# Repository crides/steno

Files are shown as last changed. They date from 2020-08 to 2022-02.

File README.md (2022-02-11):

# Steno

If you are here, you are probably looking for my embedded steno work. You can find the PCB design and production files for my steno keyboards (mostly known as the batwing or just bat) in the `pcb/` directory, and the embedded steno firmware (Kolibri) and the dictionary compiler in the `qmk/` and `compiler/` directories.

The detailed info for each can be found in their own READMEs, [boards](pcb/README.md) [firmware](qmk/README.md) and [dictionary compiler](compiler/README.md).

There's a overly simple and fairly outdated [demo](https://youtu.be/yKcQSxQE79Y).

## What's Steno(graphy)?

If you don't know what stenography is, it's a short hand system primarily used by court reporters and captioners for note taking at a very high speeds. The English stenography system uses a special keyboard with only 23 keys on it, and the keys are meant to be pressed at the same time, producing combinations called chords. When combined together and translated through an engine, it can be used to input at very high speeds (professional stenographers need to reach above 225 wpm). Due to the price of commercial steno machines, free and open source alternatives started appearing, the most prominent among which is [Plover](https://github.com/openstenoproject/plover), which acts as a keyboard emulator that can translate chords from a \$20 gaming keyboard into words efficiently. A lot of ideas here are inspired by Plover.

If you want to go a bit more in depth, you should check out [this video](https://www.youtube.com/watch?v=JsRTTD9k2ME) by Aerick, or this [PyCon talk](https://www.youtube.com/watch?v=Wpv-Qb-dB6g) by Mirabai Knight, the creator of Plover.

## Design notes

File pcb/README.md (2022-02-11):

# Embedded steno boards

These are the steno keyboards I designed and built, almost all of which has some form of hardware support for a embedded steno engine. These are just a list for more or less steno centric designs though, you can find my other boards using embedded steno like the [fissure v3](https://github.com/crides/fissure) and the [fusion](https://github.com/crides/fusion).

## Version 4

Version 4 is/are being designed as a more general board for others to use. There have been some people in the community requested me to sell some form of embedded steno board, and hardware vendors have yet to integrate the system (which on hardware is at least a flash chip). So these design(s) are meant to be easier to manufacture or assemble for the people printing their own.

## Version 3b / Bluebat

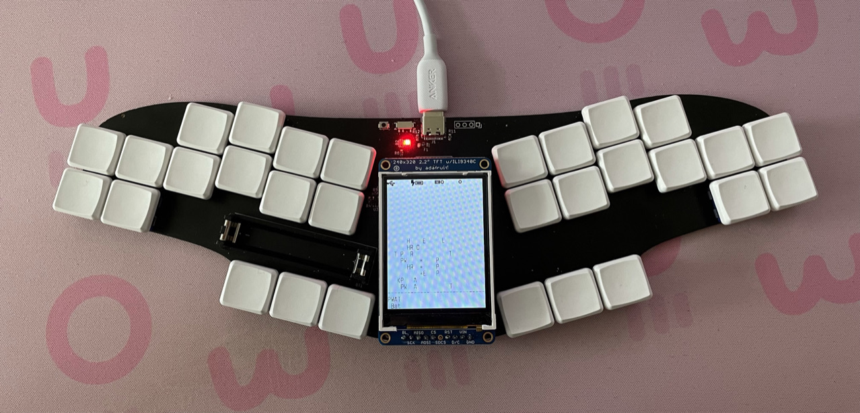
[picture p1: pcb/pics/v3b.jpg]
Picture from Jen/@sammdot: 

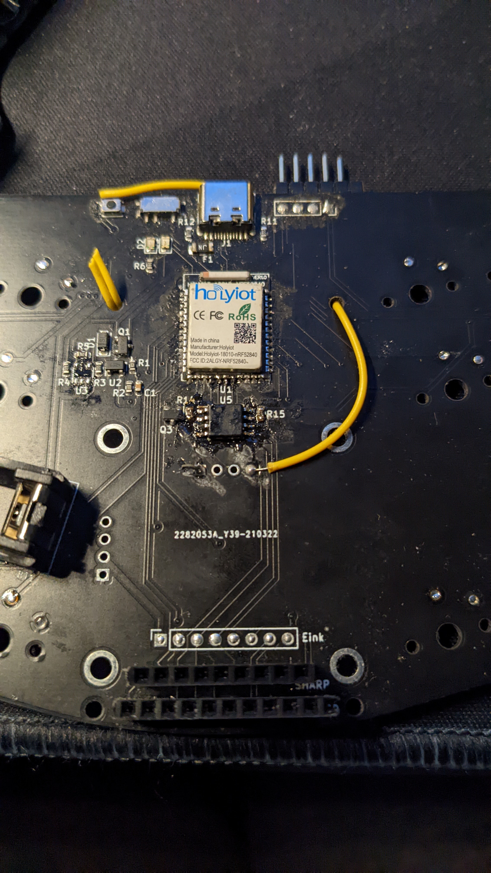
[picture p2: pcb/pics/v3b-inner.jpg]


This is the screen testing platform for future designs with BLE versions of the bat. It was meant to compare the characteristics and power consumption of OLEDs, Eink display, Sharp memory display and the 2.2 inch LCD used in version 2 & 3. This version is not actually open sourced, as it was meant to simply be a personal testing board. The only reason it's here is because one was built for Jen/@sammdot as she requested one bat for polishing the UI (and the ATMega32u4 based ones, i.e. all previous versions, don't have enough flash for a good UI to be built without compromising other features).

## Version 3

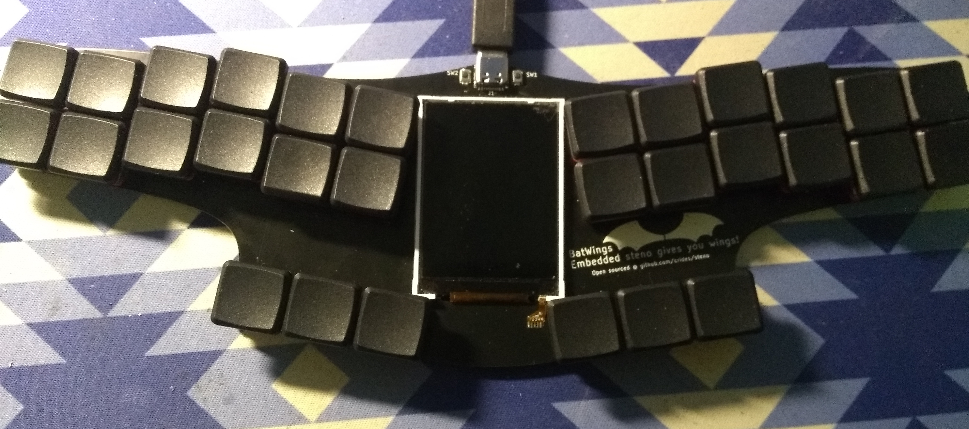
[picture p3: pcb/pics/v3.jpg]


Version 3 is the public testing version. This is done so that I can get more feedback from the community. This version uses basically the same design from version 2, but adopts a [raw screen module](https://www.aliexpress.com/item/32417585937.html) so that the cost of building is much cheaper. The other components are pushed to the back of the board as I imagine there wouldn't be much room at the front. This caused me a bit of trouble as I still want to put the diodes for the switches at the front, underneath the switches so that they are hidden. But that means I needed to hand solder the diodes while the other components are assembled at JLCPCB (they only support one sided assembly). As this was a public version, I changed the stagger of the keyboard to mimic that of Georgi's, but retained the relative position between thumbs and fingers (specifically thumb home and index home).

This version has been sent out to 9 other testers (I have one for testing) which helped me fix the dictionary downloader and polish the dictionary editing interface a bit more.

## Version 2

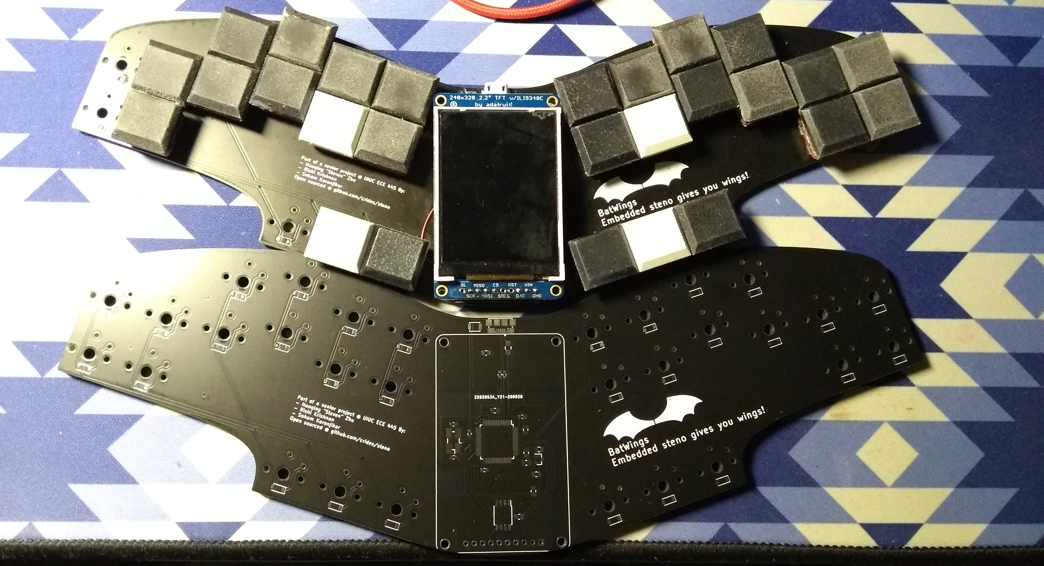
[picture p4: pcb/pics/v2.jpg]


Version 2 is the one done as a class project (ECE445, Senior Project Labotory) and you can see the class number as a branch containing the work done there (it's been merged a long time ago of course). This is also the point where I ask the community for a name of the board, and that's where BatWings (or simply bat) comes from, from a suggestion by Jane/Germ/HardAsMagnets.

The main difference of this version is that it embeds the MCU onto the board itself (per course hardware requirements), includes a [much larger screen](https://www.adafruit.com/product/1480), and starts to use Bezier curves all over the board. Note that the one pictured is the first revision where the design is not electrically sound: I forgot a level shifter for the 5V MCU to interface with a 3.3V flash. This was not a problem before as the feather I was using runs the MCU at 3.3V and 8MHz. You could see the bodge wires under the screen if you look closely

This is also the point where me and my team added command formats so that the firmware can start to support a larger portion of Plover's builtin commands, and changed the dictionary format to a simpler and more regular one based on a single level of hashmap.

## Stenophone

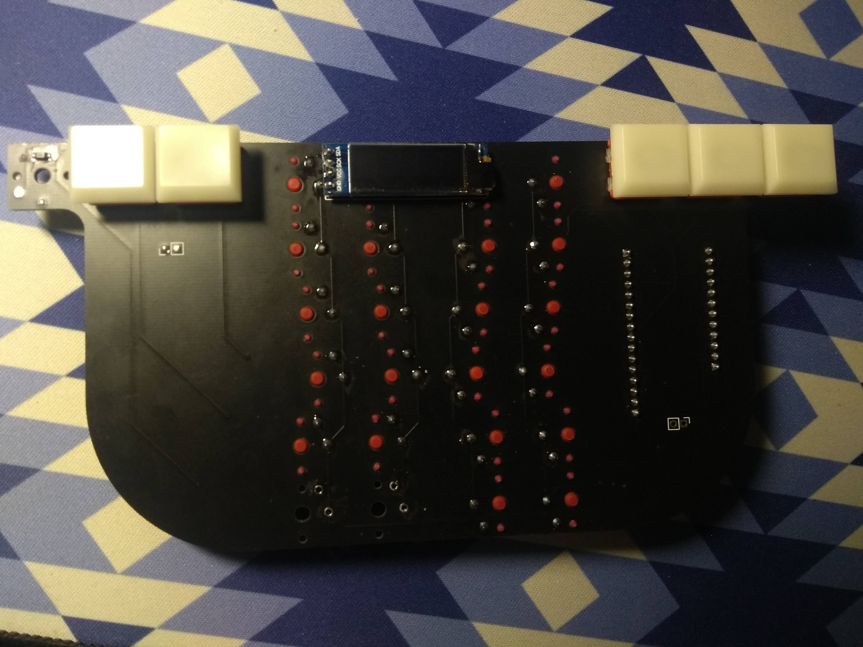
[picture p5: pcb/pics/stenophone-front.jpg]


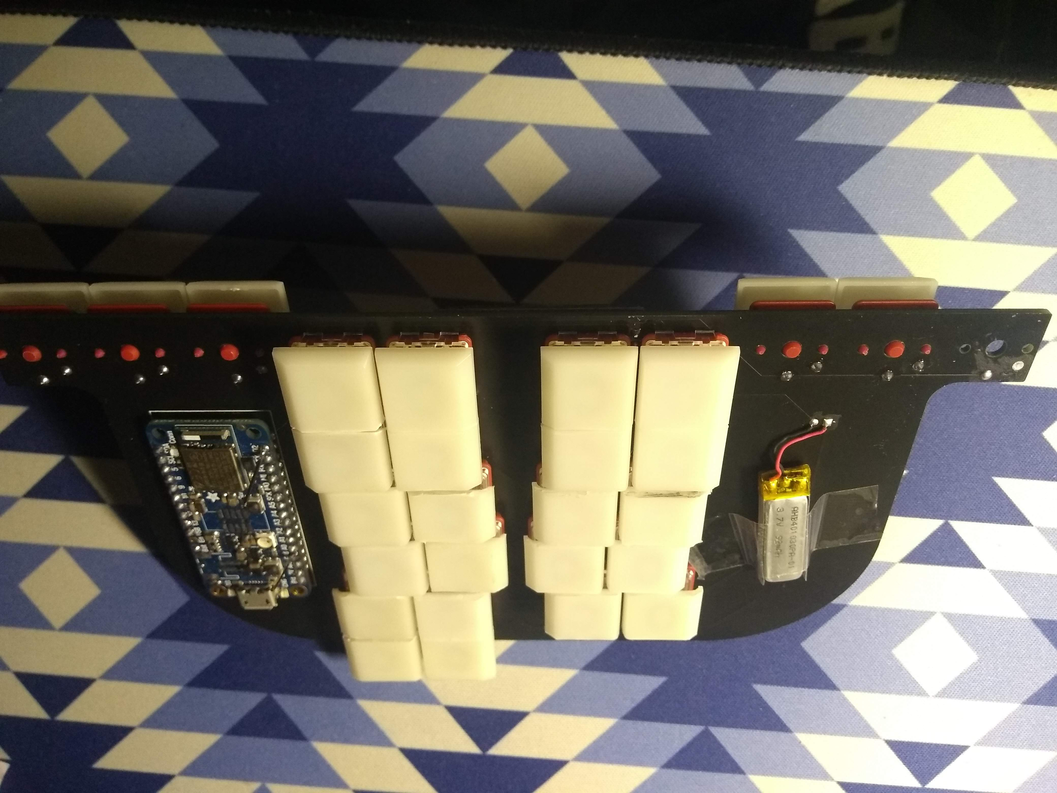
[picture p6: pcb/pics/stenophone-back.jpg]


This is a experimental version aimed to bring hardware steno to phones, so that one might be able to steno on the go (like on the bus, generally when you don't have a place to sit down). The idea is that you put this keyboard on the back of your phone, and your fingers reach to the back to press the keys, and your thumb will go over the phone to reach the vowels. This version is really only for testing out the idea, therefore a lot of the design aspects are still incomplete (for example see the battery location on the back). This version only differs in layout compare to the other ones, and uses the same steno firmware. It still uses BLE, as the plug on the phone will be simply blocked by hands.

## Version 1

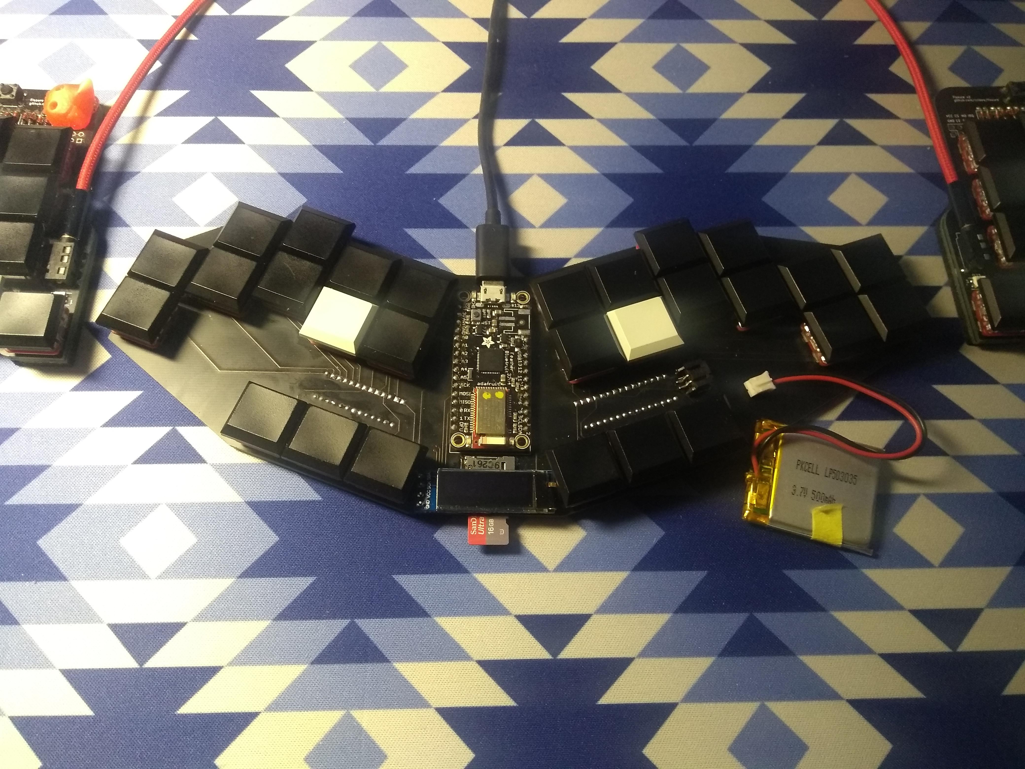
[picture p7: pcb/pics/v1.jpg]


Version 1 is a much better improvement over the first. This time I chose a split layout, but on the same board so I may use it on the go. The 2 halves are rotated 20 degrees each, so my hands won't have to bend much since it's not a actual split board. Like [my split keyboard](https://github.com/crides/fissure), this version also includes high levels of columnar stagger. I also put the MCU back to a normal position, so I don't have to worry about the underside of the keyboard anymore. This version also added a JST Li-ion battery plug (although in a weird position), a OLED for status display, a SOIC8 for experimenting with a QSPI flash, and a sdcard slot under the OLED screen.

Note the location of the sdcard; this is when it's not properly inserted to show the location. Also note the weirdly large battery and JST plug location.

## Version 0

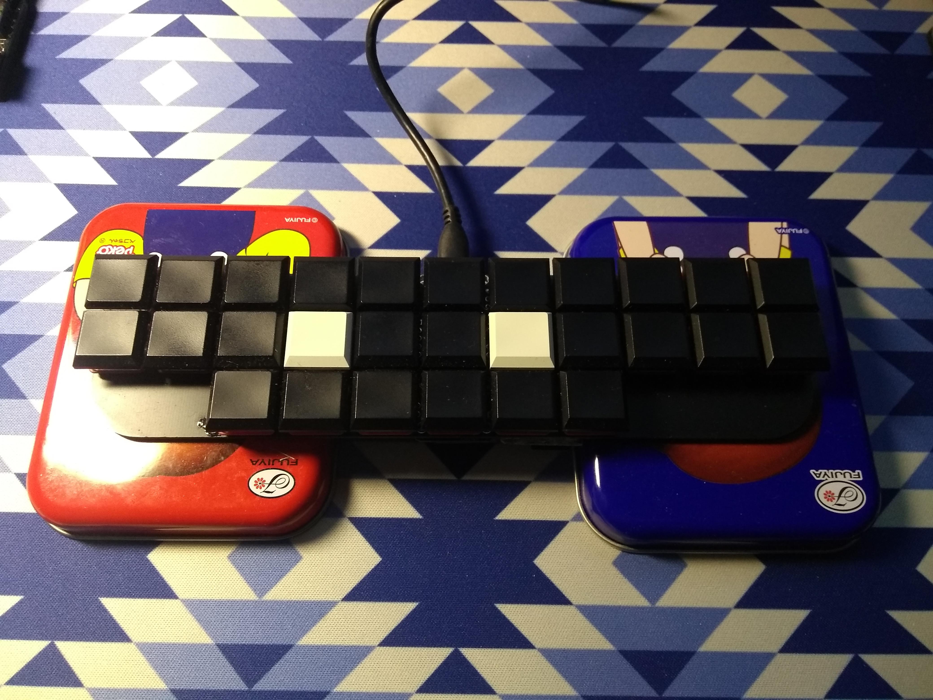
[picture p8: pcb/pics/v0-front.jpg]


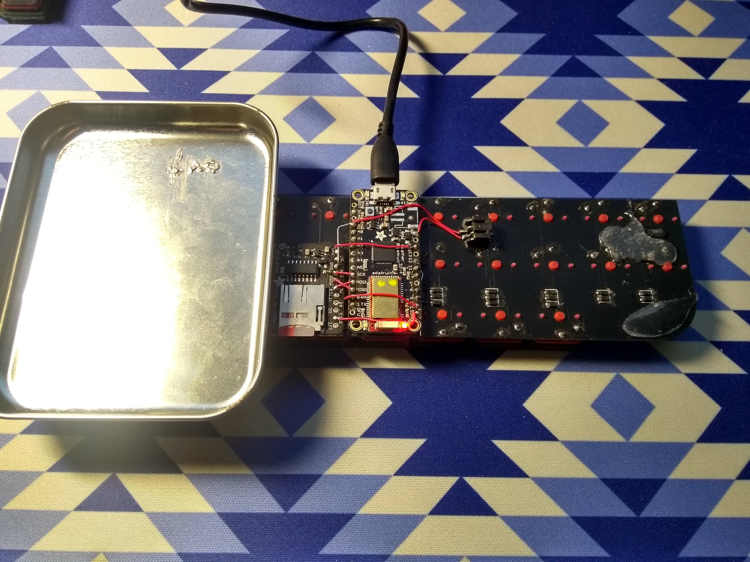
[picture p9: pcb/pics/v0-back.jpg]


The version 0 board is just a experimental board, with a small form factor while keeping the 11 column of keys needed. The number bar is missing, just like the Georgi, and the number keys are placed at either side of the vowels. As I was just starting to practice steno, I didn't know much about the dimension of a steno keyboard that I would feel comfortable using, so I simply used a ortholinear layout. In order to keep the form factor small, I tried to put the MCU under the PCB, so that it doesn't take any extra space on the PCB itself. But since I'm not used to doing that, it caused some issues when I later tried to modify the board and in normal usage.

Note the candy boxes I used to lift the board up so it's stable. Also note the sdcard slot and the bodges I did to accomodate the dictionary in the firmware.

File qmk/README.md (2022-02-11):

# Kolibri - a embedded steno firmware

Note: this belongs in the `qmk/` directory as this project began before ZMK (and if you must, KMK) did, and I haven't yet changed the directory name yet.

This is (as I know of) the first open source attempt of putting a stenography engine into a keyboard. Heavily inspired by Plover and Dotterel, this is **not** an attempt at a full featured engine, rather an engine that include the very basic features. The system is originally designed for a ATMega32u4 + a 16MB SPI NOR flash, based on the [QMK firmware](https://qmk.fm), however it's possible to port it to other hardware. Currently, the available features are:
- Strokes to text translation
- Some support for Plover-style commands. These are compiled into the dictionary as internal commands, and all but the retroactive commands are supported, with slightly different semantics.
- Optional screen UI displaying paper tapes and last translation.
- Optional on-board dictionary editing through the screen. Possible to add, remove or edit (remove & add) entries, but the translation is currently text only.
- Optional dictionary import possible through a Mass Storage Device (i.e. the keyboard can show up as a USB drive, allowing the new dictionary to be "copied" in without additional software)
- English orthography, i.e. automatically correcting the spelling using the word and suffix without additional entries.

Conversion of on-board dictionary back to Plover JSON and on-board entry lookup (and maybe suggestions) are planned for the future but not implemented.

## Usage

### Dictionary Loading

To load your personal dictionary onto the board, you need to grab the [compiler](../compiler). After compiling your dictionary into a binary file, you need to get the keyboard into dictionary loading mode (if your hardware supports it). On the public testing Bat board, this is done by plugging in while holding the button to the left of the USB port. The keyboard will then show up as a Mass Storage Device (i.e. a USB drive-like thing). Just drag the compiled dictionary into the drive, and waiting for the transfer to complete will complete the process. Note that this is a fake USB drive, and any files shown doesn't work like normal files, i.e. deleting and renaming won't work. It's just a standard workaround to flash embedded devices with binaries so that no additional software is needed.

With your personal dictionary loaded, just use the keyboard to steno like you would with Plover!

### Dictionary Editing

Use `TKUPT` (Plover default) or whatever you have `{PLOVER:ADD_TRANSLATION}` mapped to to start editing the dictionary. The compilier substitutes this commands to editing the dictionary because this would make it easier for Plover users, even though the behavior is very different. After entering the dictionary editing mode, you'll be asked to enter the strokes, as you would in the Plover interface. After pressing `R-R` (enter; key is hardcoded), the entry would be searched for, and if the entry doesn't exist, as is the case in adding a new entry, the user would be asked to enter the translation. Again, note that only pure text is supported currently. If an entry is found, a prompt would show up asking if the user want to edit the corresponding entry. If `R-R` is pressed, then the old entry is removed, and the interface would proceed to translation entering stage. If `*` (also hardcoded) is pressed, then the operation would be aborted. During the translation entering stage, if `R-R` is pressed, then the translation would be checked. If there's no text entered, then nothing would be done at this stage. Otherwise, the text would be added as a translation to the strokes entered before.

The flowchart below should help explaining things better (red boxes are actual states in the firmware, dashed arrows are automatic transitions, and solid lines are transitions that correspond to user actions).

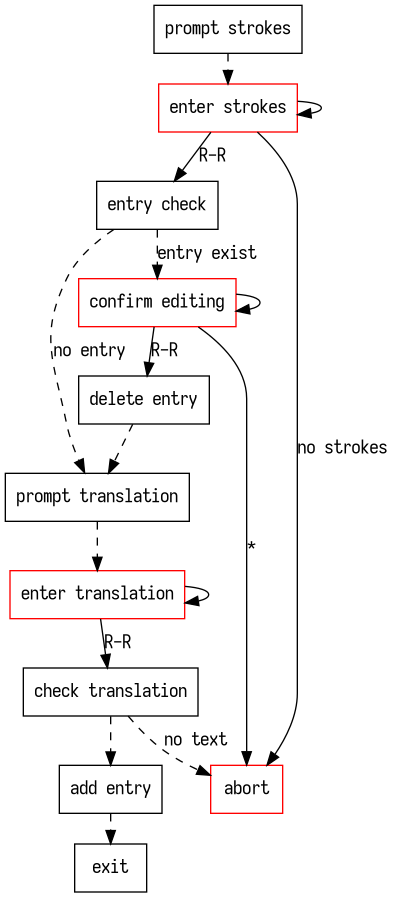
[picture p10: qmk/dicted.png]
dict editing flowchart


### Compiling the Firmware

Make sure you have the requirements for compiling and flashing firmware. This should be GNU `make`, `avr-gcc`, `avr-binutils`, and `dfu-programmer`. Then you need to use [my QMK fork](https://github.com/crides/qmk_firmware), and put/link this directory in/from `qmk_firmware/keyboards`. Configure the matrix in `config.h`, and modify keymaps in `keymaps/default/keymap.c` if needed.

Go to `qmk_firmware`, and do `make steno:default:dfu` to flash the firmware (I'm assuming that `qmk_firmware/keyboards/steno` is/links to this directory). You'll need to press the reset button on the keyboard to enter bootloader.

## Porting

You are likely to be using hardware already supporting the firmware. If not, the system relies on several things:
- Key holding/releasing using HID scan codes. This should be a thin (or none) wrapper around the firmware you are basing on.
- Storage handling interface. This is defined in `store.h`, and although the system is originally built on a single 16MB SPI NOR flash, you can theoretically use any storage backend or any region of one.
- Display/UI handling interface. This is defined in `disp.h`, and handles the UI at each stage when the interface need to change.

### Building Compatible Hardware

Although the system is designed for a MCU that has limited RAM and computing power, the code should be standard (but with lots of `const`) C99, and should be easily portable to any platform, as long as the requirements above are satisfied. A storage device is also needed, and I used the [W25Q128JVSIQ](https://lcsc.com/product-detail/FLASH_Winbond-Elec-W25Q128JVSIQ_C113767.html/). You can also optionally include a screen for paper tape display and dictionary editing.

## Background

Shortly after I built the [first version](../pcb/README.md#Version-1) of the steno board, I got the idea of building a plug-and-playable steno keyboard. The idea was that I can compile the dictionary into a special format that's easier for the MCU to process, and load it on to a SD card. When I type on the keyboard, the MCU then doesn't send the strokes to the PC for Plover to process, but rather process the translation by itself, and send the actual key codes to the PC. Note that I originally planned to do this on a 3.3V ATMega32u4, which runs on only 8MHz, 2.5kB of RAM, and 28kB of available application program space (the other 4k devoted to bootloader).

## Implementation

### Version 2

The core change of this version is to add the ability of editing the dictionary. Due to the nature of flash devices, it's important to keep things aligned to the erase unit size (which, for the flash I've been using, is 4KB).

The core structure has been changed to a flat hashmap for easier manipulation. The whole dictionary is divided into 3 parts: entry buckets, value blocks, and some metadata.

The entry buckets are 1M (read: 2^20) entries of 4 byte long each. Each entry (if not `0xFFFFFFFF` i.e. erased value) include a 20-bit value block offset, 4-bit stroke length, and a 8-bit entry length. Each entry is indexed by the lower 20 bits of the FNV-1a hash of the whole stroke sequence for an entry, moving on to the next bucket if there's a collision (open addressing).

The value blocks are 16-byte blocks, totalling 11MiB, managed by a block allocator that sits in the metadata section. Each bucket can point to any number of blocks that's a power of 2, i.e. each entry can take 16, 32, 64 etc. bytes. The larger blocks are always aligned to erase unit boundaries, as guaranteed by the block allocator. Each value block contains the raw strokes, the entry attributes, and the entry itself.

The block allocator is a 4-level 32-ary buddy system allocator, which will support 2^20 total blocks. This is done so that the implementation can be easier at the slight price of wasted space. At each level there are 32^n (0 &lt;= n &lt; 4) 32bit words, where each bit represent if its children is not fully used, or if the block is not used if at the bottom level. When a new block needs to be allocated, the tree is traversed to find a 1 in all the top levels, and then descend 1 level down until the bottom level, and try to find a series of 1s that matches the block size and is aligned. If not, then it'll backtrack to find a new location. After the block is allocated, all the bits corresponding to the block will be set to 0, and the bits on the upper levels are set accordingly.

The searching algorithm for stroke is a lot different from the last version. Since looking up one stroke sequence is a lot cheaper, determining the output became searching the last 1, 2, ... n strokes in the dictionary. When searching for an stroke sequence, the hash of the sequence will be computed, and the lower 20 bits will be multiplied with 16 and added `0x40000` (4MiB) to get the start of the value block. If a valid entry is found, the stroke length will be compared with the current strokes. If there's a match, then the value block will be read to check if the strokes match. If there's a match then the entry will be read.

Editing is fairly easy thanks to the new dictionary structure. Adding is just allocating a new block, writing the strokes and entry to the block, generating a bucket entry and writing it to a bucket. Removing can be as simple as removing the bucket entry (writing all `0x00`). Properly removing the entry would need erasing the bucket entry and value blocks, and freeing the blocks in the allocator. Editing is just removing and adding most of the time, but could be reduced down to just erasing and rewriting the value blocks if allocating new blocks is not needed.

Dictionary loading in version 2 uses a MSC with UF2. The device will enumerate as a HID and MSC when plugged in, and users can just drop the compiled dictionary in. This is technically only needed for the first time, and the OS reading the drive significantly slows down the startup process, and this shall be changed in the future.

Orthography was to be implemented inside firmware. The plan was to move the orthographic rules from the compiler into the firmware itself. The regex rules can be done by rewriting them in code, and the simple rules and the word list are to be restructured as prefix trees as ha are read only. The nature of the words means that a prefix tree will save a lot of storage space, but also make the searches broken into a lot of random reads. A better design still needs to be researched.

#### Issues

- Deallocation of the blocks aren't fully implemented, especially for the buckets and reset the bits in the allocator.
- The weird firmware issue in the last version seem to have went away.
- The storage space usage has gone up by a bit. This is partially due to node deduplication being not trivial. Turns out there is 680kB of repeated entries in the Plover dictionary (duplicated entries are not really a problem for the dictionary, but a potential problem for the underlying system).

### Version 1

This firmware uses the [QMK firmware](https://qmk.fm), but strips off any useless features for a fully steno board, like layers. It uses the steno driver, but intercepts all the strokes by using `send_steno_chord_user`. Instead of sending them off to the host, the firmware performs several look ups in the dictionary, parses the entry, and outputs the needed key strokes. Loading dictionaries is done by implementing a raw HID device and receiving packets from a PC using the compiler.

The binary dictionary is structured as a prefix tree on the strokes. The prefix tree structure was chosen because I thought it would make it easier and more space efficient to manage the dynamically sized stroke sequence better, and the nature of steno means there will be a fair amount of overlapping between the prefix of the strokes. Each sequence of strokes is broken down into edges, which each one representing one stroke. Each node will either be an entry in the dictionary or an intermediate node on the path to one. Each node will contain a hashmap of a stroke mapping to the address of a child node, or a linear array of the stroke and address pairs sorted on the stroke if the number of children is less than 8. This is done to save space on the smaller nodes, and there are a lot of them in the Plover dictionary. In order to achieve good performance, the hash is calculated using the FNV-1a hash function, and the capacity of the hashmap is the prime right after N times the number of children, where N was chosen to be 6 in the latest revision. The entry and the length, along with the capacity (not size) of the hashmap or the size of the linear array and all of its key-value pairs, and finally the attributes (the next section; not in order).

The header for a node, that is, everything before the dynamically sized stuff (i.e. entry and children). This is immediately followed by the entry with length `entry_len` and the children structure (which could be either a hashmap or a sorted array).
```c
typedef struct __attribute__((packed)) {
    uint32_t node_num : 24;
    uint8_t entry_len;
    attr_t attrs;
} header_t;
```

In order to support Plover commands but to reduce the complexity, those are implemented as attributes of a entry (with the capitalization and space control attributes). They are simply flags in the entry of the compiled dictionary, and they are evaluated when the outputs are you evaluated, changing the output or changing the state of the system which will go on affecting the next output along with the next entry attributes.

The searching algorithm is meant to take advantage of the prefix tree structure of the dictionary. Instead of looking up the stroke sequence directly which would require walking the tree multiple times, we keep an internal array of "search nodes". Each time a user inputs a stroke, the firmware will look up the stroke in the children of the search nodes and the root node. If any new nodes are found, those become the new search nodes. Out of the new search nodes, the one with the longest match with an entry will be used, and the output will be evaluated and sent to the host. This way of searching strokes makes more efficient, but also added some interesting problems to how a search path should be terminated, and how an entry is actually selected.

#### Issues

Sometimes the firmware goes crazy and seems to get stuck in an infinite loop, although there doesn't seem to be anything in my firmware that creates one directly. It could be one related to unhandled state transitions or something like that.

Simple editing could be easily supported, but was not. As there are a lot of empty space in the hashmap, it's easy to put a new node at the very end of the dictionary (but there was no way of knowing that quickly...), and overwrite an empty entry in the hashmap. However, if there are too many children in a node, it's possible to just add a new node at the end, but the whole old node will be wasted, and it's hard to reuse that space again, as the node is not aligned to erase unit boundaries.

## Future Work

- Add optimization that reuse the common parts of words. Currently, whenever a new entry is inputted, the old entry would always be deleted, regardless whether there's a common part or not. This is because, in order to save memory, only the length of the previous stroke is recorded, and the easiest way would just to delete what we had entered before and reenter the whole thing. The easiest way to add the optimization is to make a buffer for the previous output, and compare how much has changed. This however would not work when undos have occurred. The next easiest solution would be to read in the previous entry every time we want to output something, and evaluate the entry and do the comparison. This however, might cause performance issues. The most complete way would be to store the entire output in the previous history entry.

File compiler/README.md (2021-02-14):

# Dictionary Compiler

In order to get fast dictionary read speed from a not very powerful MCU, the dictionary need to be compiled to a more MCU friendly format. This generally mean a well structured binary format with as little as variable sized data as possible. We don't want to have dynamic sized data because that either means we need to have terminating markers (think null terminated strings in C) and pointers (which can be good a lot of times, but also wastes space in unneeded times). In this case, the size of a single stroke is fixed, as it can be represented as a single 23 bit integer. But a whole sequence of strokes would be of dynamic size. The entry would have to be dynamic sized.

## Version 2

In the version 2 design, a lot of the work is to be handled by the MCU (including orthographic stuff), so the compiler was only responsible for bootstrapping the dictionary. The general algorithm of compiling is the same as version 1, and the rest of the dictionary structure can be found in the firmware documentation. The only notable difference would be that the binary is directly converted to UF2 for flashing.

## Version 1

The compiler is implemented in Rust, and is made up of 3 main parts: orthographic transform, dictionary compilation, and dictionary downloading.

### Orthographic Transform

Plover does this in the runtime, and this is needed to correctly bridge the gap between syllables and the actual spelling. For example, if you stroke `RUPB/-G` the output should be "running" and not "runing". My implementation follows [Dotterel](https://github.com/nimble0/dotterel) (which is a steno engine on android devices), and the orthographic rules data is converted from the one used in Dotterel. It uses some regex rules that match and replace the word when it's followed by a suffix (i.e. an entry that has no space before it) and a big dictionary to check if the result is a real word or not. Although it's possible to put a regex engine in a AVR chip, it's not that easy to implement it. And it's only the rules themselves, the word list would require a lot more memory to handle. In addition, we also need to check if several regexs match or not, which is very expensive.

Hence, I chose to do it at the dictionary level. This can save the amount of resources required to fix orthographic problems, but also only the first level rule application is done, so some repeated application of suffixes in this implementation will be incorrect. The compiler first load the dictionary, filter out all the suffixes, apply them to each word in the dictionary, and at the end check if the result is a word or not. If it is, then we add the new stroke and entry into the dictionary.

### Dictionary Compilation

Once we have a dictionary that has undergone correct orthographic transformation, we can compile it into binary form. The dictionary strucutre will be discussed in detail in the firmware documentation, but basically the JSON dictionary is converted to a prefix tree in binary.

When the entries are parsed, the commands, key codes, and raw text are concatenated together into a single chunk according to the commands. For every entry, a new state is created, and the commands will mutate the state, which goes to influence how the next texts are concatenated. At the end, this will output one piece of text and some attributes. This is also done to reduce the amount of resources needed at runtime to parse all the commands.

Finally, all the nodes are fed into a big binary buffer for output. When each node is added, its entry text and attributes are converted to binary and added to the buffer. Its children are added recursively, and the starting address of the node is recorded. The strokes and the addresses of the nodes that they lead to are then put into a simple linear probing hash map, which can be converted to binary easily.

### Dictionary Downloading

Currently, the dictionary downloading mechanism is implemented in the raw HID interface that QMK provides, so is is is this part of the compiler implements a communication protocol that talks to the MCU and transfers the compiled dictionary over. The current protocol uses a packet length of 64 bytes. Every packet contains a header, operation ID, some parameters, and the CRC of the packet. Every write contains 28 groups of data length and a CRC. For each of these groups, a packet with only raw data (no header, operation ID etc.) would be sent, and the ACK from the MCU would be waited for.

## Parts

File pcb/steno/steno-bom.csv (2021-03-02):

Comment | Designator | Footprint | LCSC Part #
22pF | C2,C1 | C_0603_1608Metric | C1653
1uF | C4,C3,C9,C10 | C_0805_2012Metric | C28323
0.1uF | C7,C6,C5 | C_0603_1608Metric | C14663
10uF | C8 | C_0805_2012Metric | C15850
220Ω | R10,R9,R8,R7 | R_0603_1608Metric | C22962
5.1k | R12,R11 | R_0603_1608Metric | C23186
22Ω | R2,R3 | R_0603_1608Metric | C23345
10k | R6,R5,R4,R1 | R_0805_2012Metric | C17414
ATmega32U4-AU | U1 | TQFP-44_10x10mm_P0.8mm | C44854
MCP1700-3302E | U3 | SOT-23 | C39051
SRV05-4 | U6 | SOT-23-6 | C85364
16MHz | Y1 | Crystal_SMD_EuroQuartz_MT-4Pin_3.2x2.5mm | C13738

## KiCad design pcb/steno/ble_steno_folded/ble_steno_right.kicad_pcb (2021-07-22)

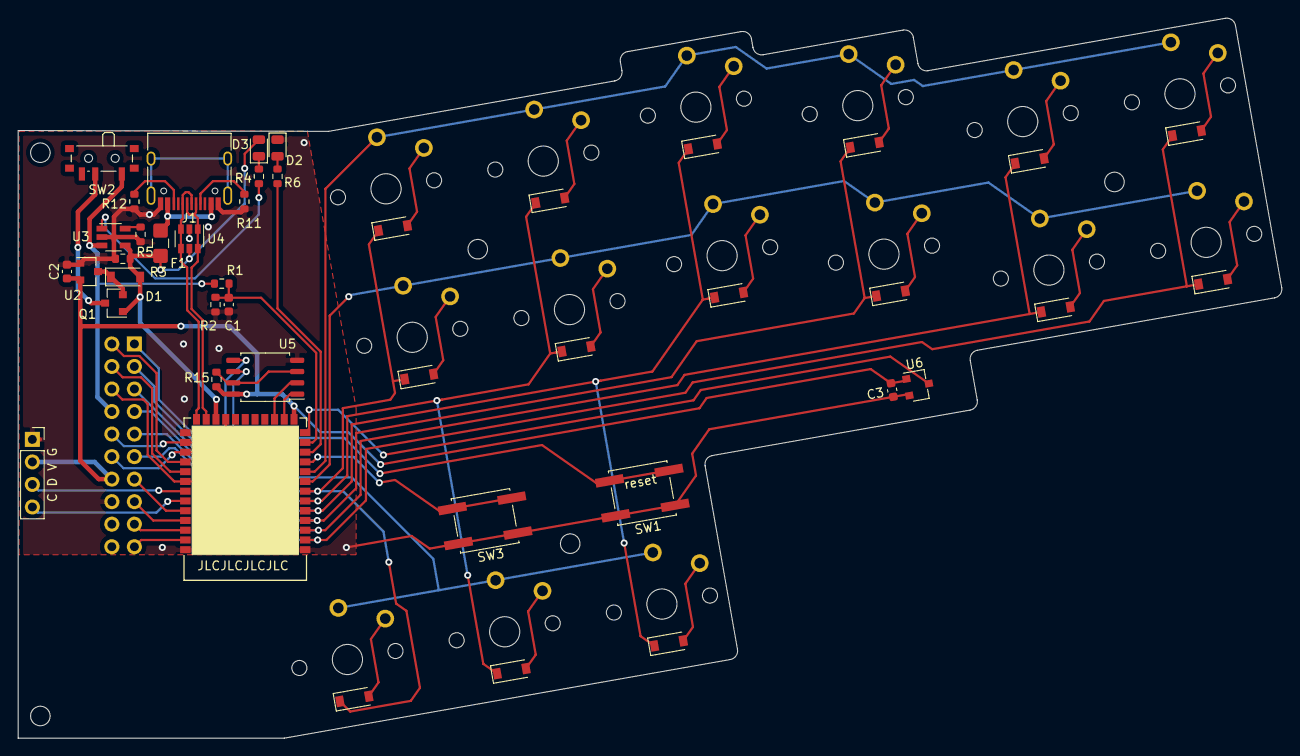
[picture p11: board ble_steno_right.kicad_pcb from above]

Board: 2 copper layers, 142.5 x 81.2 mm, 44 parts (1 on the bottom side), 42 nets.

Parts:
C1: 10nF; C_0603_1608Metric
C2: 1uF; C_0603_1608Metric
C3: 0.1uF; C_0603_1608Metric
D1: 1N5819; D_SOD-123
D2: BLUE; LED_0805_2012Metric
D3: RED; LED_0805_2012Metric
F1: Polyfuse_Small; Fuse_1206_3216Metric_Castellated
J1: USB_C_Receptacle_USB2.0; USB_C_Receptacle_HRO_TYPE-C-31-M-12
J2: Conn_02x10_Odd_Even; PinHeader_2x10_P2.54mm_Horizontal
J4: Conn_01x04_Female; PinSocket_1x04_P2.54mm_Vertical
K1, K2, K3, K4, K5, K6, K7, K8, K9, K10, K11, K12, K13, K14, K15: 1N4148W; PG1350
Q1: AO3401A; SOT-23
R1, R2: 2M; R_0603_1608Metric
R3: 100k; R_0603_1608Metric
R4, R6: 1k; R_0603_1608Metric
R5, R15: 10k; R_0603_1608Metric
R11, R12: 5.1k; R_0603_1608Metric
SW1, SW3: SW_Push; SW_SPST_EVQQ2
SW2: SW_SPDT; SW_SPDT_PCM12
U1: Holyiot_18010_no_underside
U2: MCP1700-3302E_SOT23; SOT-23
U3: LTC4054ES5-4.2; TSOT-23-5
U4: SRV05-4; SOT-23-6
U5: MT25QL128ABA1ESE; SOP-8_5.28x5.23mm_P1.27mm
U6: AH1806-W; SC-59

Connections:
BAT: J2.8, R1.1, SW2.1, U3.3
BAT_MEAS: C1.1, R1.2, R2.1, U1.12
BLUE: R6.1, U1.11
BTN: SW3.2, U1.10
COL1: J2.11, K6.2, K12.2, U1.2
COL2: J2.9, K5.2, K11.2, U1.3
COL3: J2.7, K4.2, K10.2, U1.4
COL4: J2.5, K3.2, K9.2, K15.2, U1.5
COL5: J2.3, K2.2, K8.2, K14.2, U1.6
COL6: J2.1, K1.2, K7.2, K13.2, U1.7
D+: J1.A6, J1.B6, U1.45, U4.3, U4.4
D-: J1.A7, J1.B7, U1.46, U4.1, U4.6
FLASH_CS: U1.54, U5.1
GND: C1.2, C2.2, C3.2, D2.1, J1.A1, J1.A12, J1.B1, J1.B12, J2.16, J4.1, R2.2, R3.2, R5.2, R11.1, R12.1, SW1.1, SW3.1, U1.1, U1.32, U1.44, U2.1, U3.2, U4.2, U5.4, U6.2
LCD_CS: J2.19, U1.33
LCD_DISP: J2.15, U1.35
LCD_EIN: J2.13, U1.36
LCD_EMD: J2.17, U1.34
MAGNET: U1.13, U6.3
MCU_BAT: Q1.3, SW2.2
MISO_DQ1: U1.53, U5.2
MOSI_DQ0: J2.10, U1.43, U5.5
unnamed: D1.1, Q1.2, U2.3
unnamed: D2.2, R6.2
unnamed: D3.1, R4.2
unnamed: J1.A5, R11.2
unnamed: J1.B5, R12.2
unnamed: R4.1, U3.1
unnamed: R5.1, U3.5
unnamed: R15.2, U5.3, U5.7
ROW1: J2.2, U1.41
ROW2: J2.4, U1.40
ROW3: J2.6, K13.1, K14.1, K15.1, U1.39
ROW4: K1.1, K2.1, K3.1, K4.1, K5.1, K6.1, U1.9
ROW5: K7.1, K8.1, K9.1, K10.1, K11.1, K12.1, U1.8
RST: SW1.2, U1.48
SCLK: J2.12, U1.42, U5.6
SWC: J4.4, U1.37
SWD: J4.3, U1.38
VBUS: D1.2, D3.2, F1.1, Q1.1, R3.1, U1.47, U3.4, U4.5
VCC: F1.2, J1.A4, J1.A9, J1.B4, J1.B9
VDD: C2.1, C3.1, J2.14, J4.2, R15.1, U1.55, U2.2, U5.8, U6.1

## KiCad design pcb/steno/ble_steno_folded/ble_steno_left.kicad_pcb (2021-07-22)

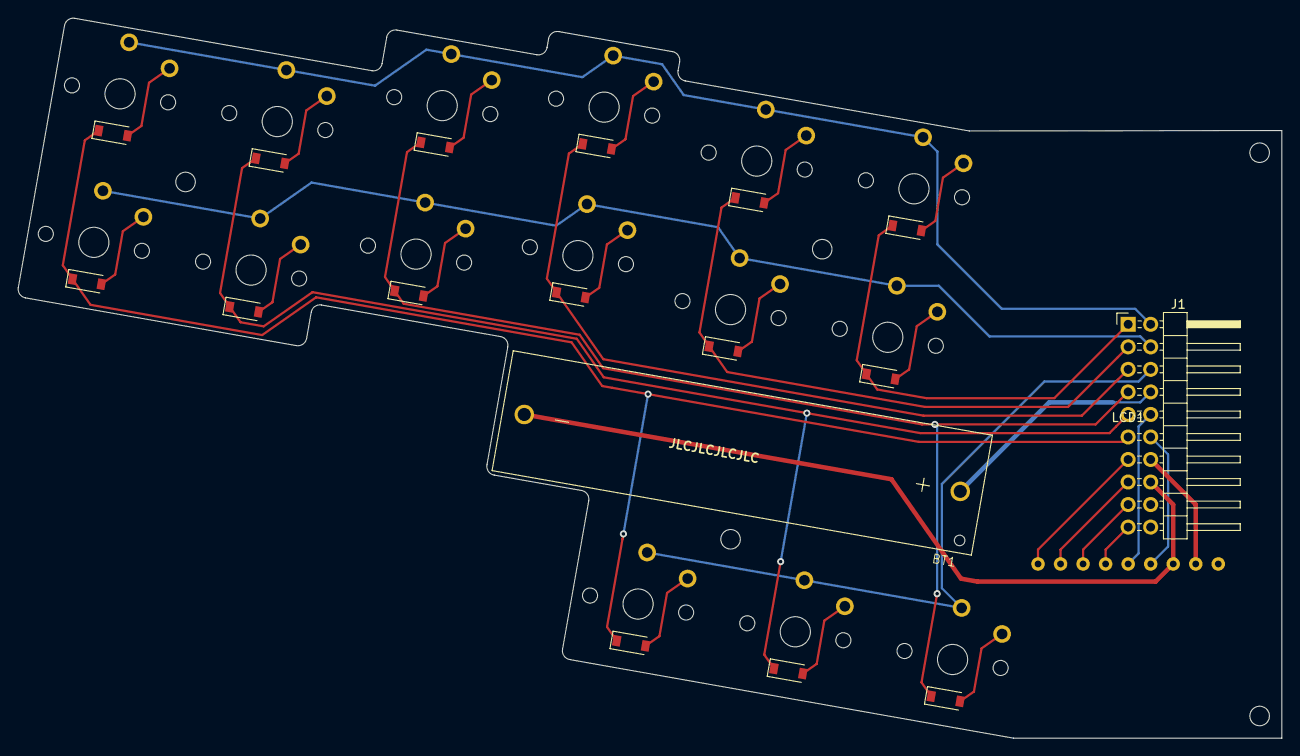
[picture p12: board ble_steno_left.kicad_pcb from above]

Board: 2 copper layers, 142.5 x 81.2 mm, 18 parts (0 on the bottom side), 18 nets.

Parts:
BT1: Battery_Cell; BA1AAAPC
J1: Conn_02x10_Odd_Even; PinHeader_2x10_P2.54mm_Horizontal
K1, K2, K3, K4, K5, K6, K7, K8, K9, K10, K11, K12, K13, K14, K15: 1N4148W; PG1350
LCD1: SHARP_LCD; Adafruit_Sharp_Memory_Display_1.3in_no_mounting

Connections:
+3V3: J1.14, LCD1.8
BAT: BT1.1, J1.8
COL1: J1.11, K1.2, K7.2, K13.2
COL2: J1.9, K2.2, K8.2, K14.2
COL3: J1.7, K3.2, K9.2, K15.2
COL4: J1.5, K4.2, K10.2
COL5: J1.3, K5.2, K11.2
COL6: J1.1, K6.2, K12.2
DISP: J1.15, LCD1.2
EIN: J1.13, LCD1.1
EMD: J1.17, LCD1.3
GND: BT1.2, J1.16, LCD1.7
LCD_CS: J1.19, LCD1.4
MOSI: J1.10, LCD1.5
ROW1: J1.2, K1.1, K2.1, K3.1, K4.1, K5.1, K6.1
ROW2: J1.4, K7.1, K8.1, K9.1, K10.1, K11.1, K12.1
ROW3: J1.6, K13.1, K14.1, K15.1
SCK: J1.12, LCD1.6

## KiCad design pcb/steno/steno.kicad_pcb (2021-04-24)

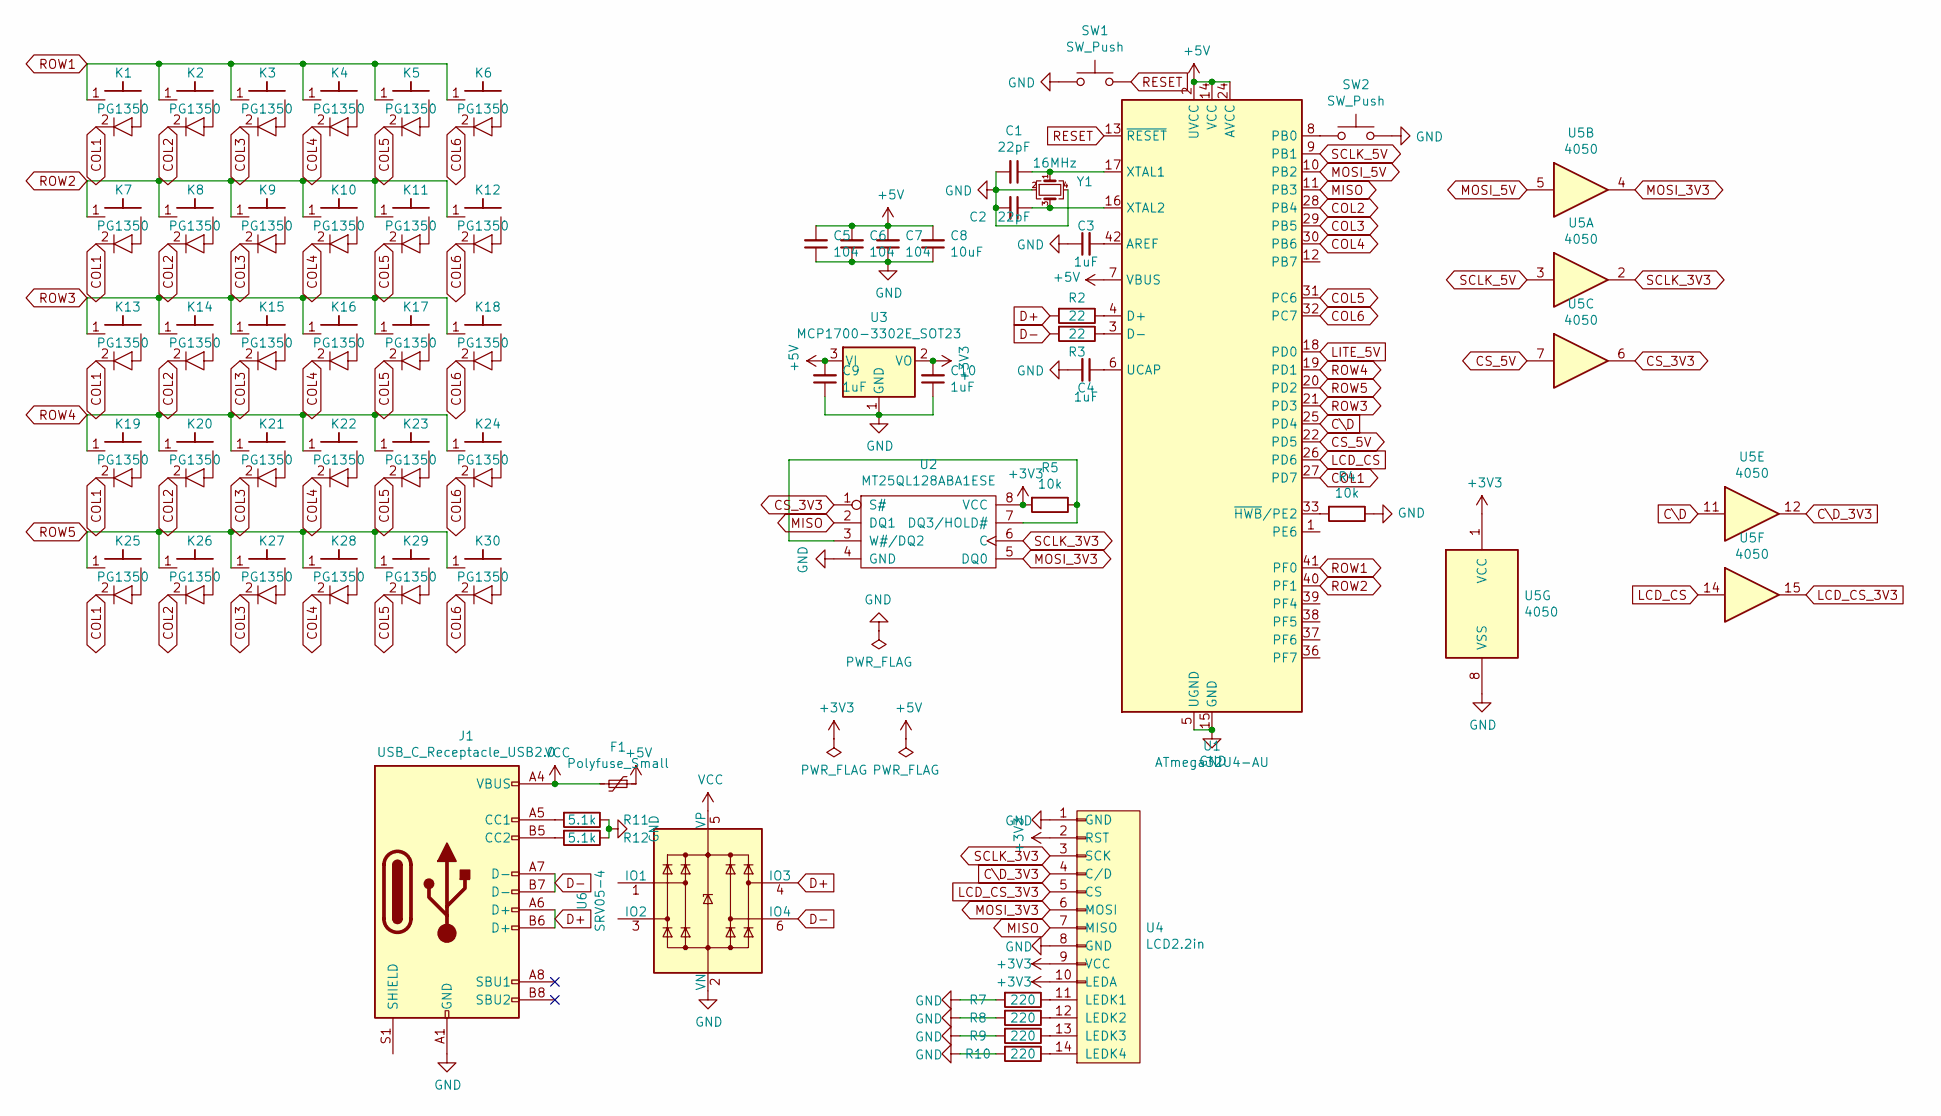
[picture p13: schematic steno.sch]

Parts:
C1, C2: 22pF; C_0603_1608Metric
C3, C4, C9, C10: 1uF; C_0805_2012Metric
C5, C6, C7: 104; C_0603_1608Metric
C8: 10uF; C_0805_2012Metric
F1: Polyfuse_Small; Fuse_1206_3216Metric_Castellated
J1: USB_C_Receptacle_USB2.0; USB_C_Receptacle_HRO_TYPE-C-31-M-12
K1, K2, K3, K4, K5, K6, K7, K8, K9, K10, K11, K12, K13, K14, K15, K16, K17, K18, K19, K20, K21, K22, K23, K24, K25, K26, K27, K28, K29, K30: PG1350
R2, R3: 22; R_0603_1608Metric
R4, R5: 10k; R_0805_2012Metric
R7, R8, R9, R10: 220; R_0603_1608Metric
R11, R12: 5.1k; R_0603_1608Metric
SW1, SW2: SW_Push; SW_SPST_B3U-1000P
U1: ATmega32U4-AU; TQFP-44_10x10mm_P0.8mm
U2: MT25QL128ABA1ESE; SOP-8_5.28x5.23mm_P1.27mm
U3: MCP1700-3302E_SOT23; SOT-23
U4: LCD2.2in
U5: 4050; SOIC-16_3.9x9.9mm_P1.27mm
U6: SRV05-4; SOT-23-6
Y1: 16MHz; Crystal_SMD_EuroQuartz_MT-4Pin_3.2x2.5mm

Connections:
+3V3: C10.2, R5.2, U2.8 (VCC), U3.2 (VO), U4.2 (RST), U4.9 (VCC), U4.10 (LEDA), U5.1 (VCC)
+5V: C5.2, C6.2, C7.2, C8.2, C9.2, F1.1, U1.2 (UVCC), U1.7 (VBUS), U1.14 (VCC), U1.24 (AVCC), U1.34 (VCC), U1.44 (AVCC), U3.3 (VI)
COL1: K1.2, K7.2, K13.2, K19.2, K25.2, U1.27 (PD7)
COL2: K2.2, K8.2, K14.2, K20.2, K26.2, U1.28 (PB4)
COL3: K3.2, K9.2, K15.2, K21.2, K27.2, U1.29 (PB5)
COL4: K4.2, K10.2, K16.2, K22.2, K28.2, U1.30 (PB6)
COL5: K5.2, K11.2, K17.2, K23.2, K29.2, U1.31 (PC6)
COL6: K6.2, K12.2, K18.2, K24.2, K30.2, U1.32 (PC7)
CS_3V3: U2.1 (S#), U5.6
CS_5V: U1.22 (PD5), U5.7
C\D: U1.25 (PD4), U5.11
C\D_3V3: U4.4 (C/D), U5.12
D+: J1.A6 (D+), J1.B6 (D+), R2.2, U6.4 (IO3)
D-: J1.A7 (D-), J1.B7 (D-), R3.2, U6.6 (IO4)
GND: C1.2, C2.2, C3.1, C4.2, C5.1, C6.1, C7.1, C8.1, C9.1, C10.1, J1.A1 (GND), J1.A12 (GND), J1.B1 (GND), J1.B12 (GND), R4.1, R7.2, R8.2, R9.2, R10.2, R11.1, R12.1, SW1.1, SW2.1, U1.5 (UGND), U1.15 (GND), U1.23 (GND), U1.35 (GND), U1.43 (GND), U2.4 (GND), U3.1 (GND), U4.1 (GND), U4.8 (GND), U5.8 (VSS), U6.2 (VN), Y1.2, Y1.4
LCD_CS: U1.26 (PD6), U5.14
LCD_CS_3V3: U4.5 (CS), U5.15
LITE_5V: U1.18 (PD0)
MISO: U1.11 (PB3), U2.2 (DQ1), U4.7 (MISO)
MOSI_3V3: U2.5 (DQ0), U4.6 (MOSI), U5.4
MOSI_5V: U1.10 (PB2), U5.5
unnamed: C1.1, U1.17 (XTAL1), Y1.1
unnamed: C2.1, U1.16 (XTAL2), Y1.3
unnamed: C3.2, U1.42 (AREF)
unnamed: C4.1, U1.6 (UCAP)
unnamed: J1.A5 (CC1), R11.2
unnamed: J1.B5 (CC2), R12.2
unnamed: R2.1, U1.4 (D+)
unnamed: R3.1, U1.3 (D-)
unnamed: R4.2, U1.33 (~HWB~/PE2)
unnamed: R5.1, U2.3 (W#/DQ2), U2.7 (DQ3/HOLD#)
unnamed: R7.1, U4.11 (LEDK1)
unnamed: R8.1, U4.12 (LEDK2)
unnamed: R9.1, U4.13 (LEDK3)
unnamed: R10.1, U4.14 (LEDK4)
unnamed: SW2.2, U1.8 (PB0)
RESET: SW1.2, U1.13 (~RESET)
ROW1: K1.1, K2.1, K3.1, K4.1, K5.1, K6.1, U1.41 (PF0)
ROW2: K7.1, K8.1, K9.1, K10.1, K11.1, K12.1, U1.40 (PF1)
ROW3: K13.1, K14.1, K15.1, K16.1, K17.1, K18.1, U1.21 (PD3)
ROW4: K19.1, K20.1, K21.1, K22.1, K23.1, K24.1, U1.19 (PD1)
ROW5: K25.1, K26.1, K27.1, K28.1, K29.1, K30.1, U1.20 (PD2)
SCLK_3V3: U2.6 (C), U4.3 (SCK), U5.2
SCLK_5V: U1.9 (PB1), U5.3
VCC: F1.2, J1.A4 (VBUS), J1.A9 (VBUS), J1.B4 (VBUS), J1.B9 (VBUS), U6.5 (VP)

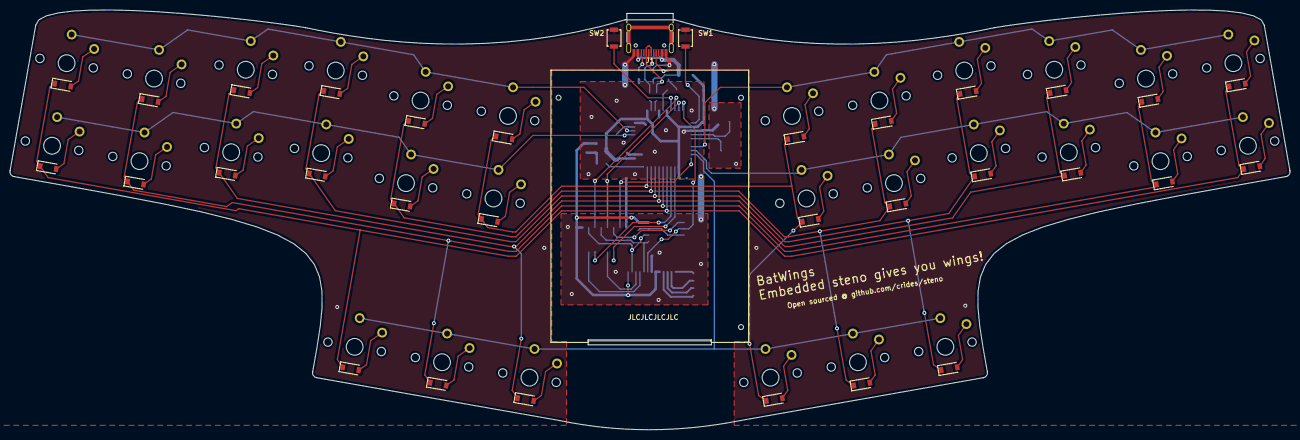
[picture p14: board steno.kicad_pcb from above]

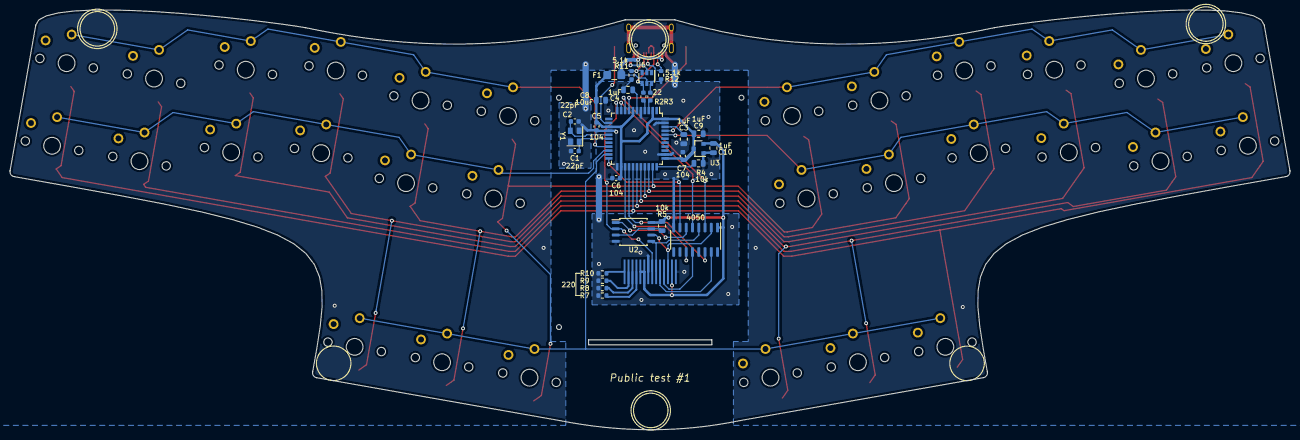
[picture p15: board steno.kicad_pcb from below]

Board: 2 copper layers, 259.5 x 85.1 mm, 61 parts (27 on the bottom side), 44 nets.

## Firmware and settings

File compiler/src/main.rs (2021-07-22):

#[macro_use]
extern crate serde_derive;
#[macro_use]
extern crate lazy_static;
#[macro_use]
extern crate bitfield;

mod bar;
mod compile;
mod dict;
mod freemap;
mod hash;
mod orthography;
#[cfg(feature = "patching")]
mod rule;
mod stroke;

use std::fs::File;
use std::io::{Seek, SeekFrom};

use clap::{App, AppSettings, Arg, SubCommand};

use dict::Dict;
#[cfg(feature = "patching")]
use rule::{apply_rules, Dict as RuleDict, Rules};
use stroke::{Stroke, Strokes};

fn main() {
    let app = App::new("compile-steno")
        .subcommand(SubCommand::with_name("test").arg(Arg::with_name("stroke").required(true)))
        .subcommand(SubCommand::with_name("hash").arg(Arg::with_name("strokes").required(true)))
        .subcommand(SubCommand::with_name("test-parse").arg(Arg::with_name("text").required(true)))
        .subcommand(SubCommand::with_name("hash-str").arg(Arg::with_name("str").required(true)))
        .subcommand(
            SubCommand::with_name("compile")
                .arg(
                    Arg::with_name("input")
                        .required(true)
                        .multiple(true)
                        .min_values(1),
                )
                .arg(Arg::with_name("output").required(true)),
        )
        .setting(AppSettings::SubcommandRequiredElseHelp);
    #[cfg(feature = "patching")]
    let app = app.subcommand(
            SubCommand::with_name("apply-rules")
                .arg(Arg::with_name("rules").required(true))
                .arg(Arg::with_name("from").required(true))
                .arg(Arg::with_name("to").required(true)),
        );
    let matches = app.get_matches();
    match matches.subcommand() {
        ("compile", Some(m)) => {
            let input_files = m.values_of("input").unwrap();
            let output_file = m.value_of("output").unwrap();

            let inputs: Vec<_> = input_files
                .map(|f| {
                    (
                        f,
                        serde_json::from_reader(File::open(f).expect("input file"))
                            .expect("parse json"),
                    )
                })
                .collect();
            let dict = match Dict::parse(Dict::merge_dicts(inputs)) {
                Ok(d) => d,
                Err(e) => {
                    eprintln!("{}", e);
                    return;
                }
            };
            let mut output_file = File::create(output_file).expect("output file");
            if let Err(e) = compile::to_writer(dict, &mut output_file) {
                eprintln!("{}", e);
                return;
            };
            println!("Size: {}", output_file.seek(SeekFrom::Current(0)).unwrap());
        }
        #[cfg(feature = "patching")]
        ("apply-rules", Some(m)) => {
            let rules: Rules = serde_json::from_reader(
                File::open(m.value_of("rules").unwrap()).expect("Cannot open rules file!"),
            )
            .expect("Rules file not valid JSON!");
            let source: RuleDict = serde_json::from_reader(
                File::open(m.value_of("from").unwrap()).expect("Cannot open dict!"),
            )
            .expect("Dict file not valid JSON!");
            let output_dict = apply_rules(&rules, &source);
            println!("\nSize: {}", output_dict.len());
            let output_file =
                File::create(m.value_of("to").unwrap()).expect("Cannot create output file!");
            serde_json::to_writer(output_file, &output_dict).expect("Write output file");
        }
        ("test", Some(m)) => {
            let stroke: Stroke = m.value_of("stroke").unwrap().parse().unwrap();
            println!("{:x}", stroke.raw());
        }
        ("hash", Some(m)) => {
            let strokes: String = m.value_of("strokes").unwrap().parse().unwrap();
            let strokes = strokes
                .split('/')
                .map(|stroke| stroke.parse().unwrap())
                .collect::<Vec<_>>();
            dbg!(&strokes);
            println!("{:x}", stroke::hash_strokes(&Strokes(strokes)));
        }
        ("hash-str", Some(m)) => {
            let s: String = m.value_of("str").unwrap().parse().unwrap();
            dbg!(&s);
            let hash = hash::hash(s.as_bytes(), None);
            println!("{:x}", hash);
            let index = hash as usize % (orthography::BUCKET_CAP - 1);
            println!("{:x}", index);
        }
        ("test-parse", Some(m)) => {
            let input = m.value_of("text").unwrap();
            match dbg!(crate::dict::parse::parse_entry(input)) {
                Err(e) => {
                    println!("{}", e.format_error(input));
                }
                Ok(v) => {
                    println!("{:?}", v);
                }
            }
        }
        _ => panic!(),
    }
}

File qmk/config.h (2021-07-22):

#ifndef CONFIG_H
#define CONFIG_H

#include "config_common.h"

/* USB Device descriptor parameter */
#define VENDOR_ID       0xFEED
#define PRODUCT_ID      0x6061
#define DEVICE_VER      0x0001
#define MANUFACTURER    Crides
#define PRODUCT         Steno
#define SERIAL_NUMBER   v2
#define DESCRIPTION     28 key steno board

#define MATRIX_ROWS 5
#define MATRIX_COLS 6

#define OLED_TIMEOUT 3000
#define OLED_DISABLE_TIMEOUT

#define MATRIX_ROW_PINS { F0, F1, D3, D1, D2 }
#define MATRIX_COL_PINS { D7, B4, B5, B6, C6, C7 }

#define DIODE_DIRECTION ROW2COL
#define DEBOUNCING_DELAY 5
#define LOCKING_SUPPORT_ENABLE
#define LOCKING_RESYNC_ENABLE
#define PREVENT_STUCK_MODIFIERS
#define UNICODE_SELECTED_MODES UC_LNX

#ifdef STENO_DEBUG
#undef NO_PRINT
#endif

#define LAYER_STATE_8BIT
#define NO_RESET
#define NO_ACTION_LAYER
#define NO_ACTION_TAPPING
#define NO_ACTION_ONESHOT
#define NO_ACTION_MACRO
#define NO_ACTION_FUNCTION

#endif

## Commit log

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2020-03-29 Trimming down SD library
    Removed `device_read` `device_read_interval` entries and corresponding
    runtime checking.
    Forced removed write support
2020-04-29 Assuming FAT blocks are continuous
    Previously, the FAT library has to read the File Allocation Table to
    determine the next block of the file. Obviously that is not cached, so
    retrieving the next block address has a very high overhead. Since for
    now the blocks seems to be continuous, we'll assume that until we have a
    new design that uses a SPI flash and USB Mass Storage
2020-05-03 Reorg directory; added PCB files
    [steno-B_Cu.gbr, steno-B_Mask.gbr, steno-B_SilkS.gbr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]
2020-05-12 Fix bug
    Previous state should look back further when inserting multi-stroke
    entries (replacing previous strokes)
2020-05-12 Move number glue check from firmware to compiler
    In Plover, an entry is automatically glued if everything is digit. Since
    the digit implementation came before the attributes, this was done in
    firmware. As something like this is static, we move it into the
    compiler.
2020-05-18 Add v2 gerber
    [steno-v2-B_Cu.gbr, steno-v2-B_Mask.gbr, steno-v2-B_SilkS.gbr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]
2020-05-18 v2 KiCAD files
    [steno-v2.kicad_pcb, steno-v2.sch, steno.kicad_pcb]
2020-05-23 Update PCB and footprints
    [steno-v2.kicad_pcb, steno-v2.sch]
2020-05-25 Fix node searching bug
    This bug currently affects words with default orthography, i.e. the ones
    that you just add a s to it, for example. This bug is discovered with
    the stroke sequence REBG/ORD/S, which should output "records", but
    was outputting "orders", as there's no orthography rules for "record"
    because you just need to add s to it, and the engine sees that "orders"
    is the longest match, and uses it.
    This is resolved by enforcing that the next non root stroke must have
    one more level than the current/last output. If that is not possible,
    than we simply use the root based node.
2020-05-25 Fixed undo bug
    Previously, `hist_undo()` puts `process_output()` one too late on the
    history entries. Basically, `process_output()` expects the last history
    entry to be on the current entry (i.e. on `hist_ind`). So
    `process_output()` will use the wrong number of backspaces.
    Also added proprocessor-guarded debug statements
    [config.h]
2020-06-01 Finish up the flash firmware
    - Set SPI to F_CPU / 2
    - Add status check after erase (was a bug)
    - Removed the FAT related stuff
    - Changed reads to work with flash
    - Uncomment custom steno engine (it worked!)
    - Parameterized message format with macros
    [flash.c]
2020-06-02 Compiler flash download done
    - Parameterized packet format with `const`'s
    - Fix frequently open/close file
    - Removed `flash-read` and `flash-write`
    - Divide packet when on page boundary
    [main.rs]
2020-06-04 Compiler: Switch to MassWrite
2020-06-14 Update PCB
    [steno-v2.kicad_pcb]
2020-06-14 v3 component placement; Removed JST connector; Added OLED footprint
    [steno-v2.kicad_pcb, steno-v2.sch]
2020-06-14 Routed and plotted v3
    [steno-v2-B_Cu.gbr, steno-v2-B_Mask.gbr, steno-v2-B_SilkS.gbr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]
2020-06-28 Add rudimentary Unicode support
    The full range of Unicode is supported, but the implementation is a
    hack. Currently, the system assumes Linux (which is what I use), and
    uses the C-S-u combo to get IBus to enter a Unicode character. In order
    to reduce complexity, the Unicode characters in the strings are
    represented with 4 bytes, a start byte with 0x01 (invalid character/HID
    code anyway), and 3 bytes representing the lower 3 bytes of the code
    point. It's a hack because the case changing code doesn't take into
    account the Unicode formats, and may or may not change the actual
    output.
2020-07-22 Remove v1 files
    [steno-v2.kicad_pcb, steno-v2.sch, steno.kicad_pcb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]
2020-07-22 Mobile steno
    [mobile-steno-B_Cu.gbr, mobile-steno-B_Mask.gbr, mobile-steno-B_SilkS.gbr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]
2020-07-22 Steno board fix
    [steno.dsn]
2020-07-22 Add hole to choc footprint
2020-07-22 Fix silkscreen and fucking flip the switches
    [mobile-steno-B_Cu.gbr, mobile-steno-B_Mask.gbr, mobile-steno-B_SilkS.gbr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]
2020-08-01 Slightly improved layout and routing
    - Moved thumb cluster to row 5 from 3
    - Make row pins be in order
    [mobile-steno-B_Cu.gbr, mobile-steno-B_Mask.gbr, mobile-steno-B_SilkS.gbr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]
2020-08-04 Split README, add pictures of boards
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2020-09-28 First PCB version
    - Use raw MCU
    - Use 5x6 matrix and 30keys (like steno phone)
    - Use SOD-123 diodes (like steno phone)
    - Use 2.2in TFT for better UX(?)
    - Lots of ground plane!
    - Add (fake?) logo and contributors
    [steno-B_Cu.gbr, steno-B_Mask.gbr, steno-B_SilkS.gbr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]
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2020-10-12 [firmware] Add basic LCD support
    - Adopted LCD library from `adafruit/Adafruit_ILI9341` and
    `adafruit/Adafruit-GFX-Library`
    - Refractored SPI stuff out from flash
    - Still need to clean up bits (e.g. last stroke/translation stuff, which was
    related to OLED)
2020-10-18 [firmware] Fix unicode and start implementing dict_edit ui
    [config.h]
2020-10-22 [PCB] Final changes
    - Add bumper locations on silkscreen
    - Add hex buffer for level shifting
    - Unify the 2 grounds into 1, removing the decoupling cap
    - Add MCU peripheral ref & value to silkscreen
    [steno-B_Cu.gbr, steno-B_Mask.gbr, steno-B_SilkS.gbr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]
2020-10-22 [firmware] Merge & fix firmware for new command formats
    This patch is not yet fully complete, but is interrupted by dictionary
    format changes. We still need to handle what cap state is passed into
    `process_output`, and properly handle `keep` and `upper` cases at the
    end of entries (transitions that happen just before the end and those
    that happen at the end are different)
    [config.h]
2020-10-23 [compiler] First steps towards new format
    Changing compiler to compile to flat hashmap structure. Divide the
    storage into 3 sections, 1 for buckets in the hash map, 1 for key value
    pairs, and the final one for keeping track of use the used blocks if the
    key value pairs section.
    Main remaining issues:
    - Block free mop still need to be added to the final compiled
    dictionary, after a format for the final MB is decided
    - Need to find better ways to find empty blocks in the free map. The
    current solution works, but only because of tests and lots of trial
    and error.
    - Probably needs to change how the words in the free map are indexed.
    Currently we assume that they are in order, sorted by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
    [main.rs]
2020-10-24 [dict] Remove some fingerspell entries & recompile for new format
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2020-11-04 [compiler] Fix issues and add utils
    - Compiling: swap length & attribute (length in front)
    - CLI: add hash strokes for testing
    - Dict parsing: add more test cases & make pure numbers glue
    - Stroke: make multiplication explicitly wrapping
    [main.rs]
2020-11-11 [firmware] Optimize LCD parts
    - Macro-ize constants
    - Minimizing calls in `vline`, `hline`, and `fill_rect` by using
    `set_addr_window` properly
    - Cut out unused font data
2020-11-11 [firmware] Fixed dict editing UI
    [lcd.c]
2020-11-13 [compiler] Fix allocator & use UF2 file format
    [main.rs]
2020-11-14 [compiler] Fix block allocator
    [main.rs]
2020-11-18 [firmware] Final demo version
    - `const`-ify variables for better reasoning
    - Turn off unused options for smaller firmware
    - Fix some dict edit issues; add ability to cancel operation
    - Display current stroke sequence and translation (only characters)
    - Slightly modify UF2 format for easier handling
    [config.h, flash.c]
2021-02-14 [firmware] Move entry length to bucket + small refractors
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2021-02-15 [PCB] Use "raw" LCD + backside components
    [steno-B_Cu.gbr, steno-B_Mask.gbr, steno-B_SilkS.gbr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]
2021-02-16 [PCB] Remove stenophone
    [mobile-steno.kicad_pcb, mobile-steno.sch]
2021-02-16 [PCB] normalize stagger + compacting
    [steno-B_Cu.gbr, steno-B_Mask.gbr, steno-B_SilkS.gbr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]
2021-02-18 [firmware] bug fixes + refractor
    - Fix some leftover incorrect assumptions when moving entry length into
    buckets
    - Rename `entry(_ptr)` to `bucket`
    - Remove sekigon QMK stuff
    - Remove SD card and (true) FAT support files
    [config.h, flash.c]
2021-02-19 [PCB] Use new PG1350 footprint + remove unneeded libraries
    [steno-B_Cu.gbr, steno-B_Mask.gbr, steno-B_SilkS.gbr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]
2021-03-02 [PCB] Remove unused footprint and gerbers
    [mobile-steno-B_Cu.gbr, mobile-steno-B_Mask.gbr, mobile-steno-B_SilkS.gbr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]
2021-03-02 [PCB] Change to USB-C connector + protection diode
    [steno-B_Cu.gbr, steno-B_Mask.gbr, steno-B_SilkS.gbr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]
2021-03-14 [PCB] Public test version
    [steno.kicad_pcb, steno.sch]
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2021-03-28 [firmware] Rule based orthography
    - bug fix for long entry searching
    - refractored out some old code
    - added regex-based orthography (treating the combination of word &
    suffix as a long virtual entry; if suffix is only adding (i.e. no
    removing on the original entry) then the suffix and any additional
    letters are treated as its own entry)
    [config.h]
2021-03-29 [firmware] Fix keep case bug
2021-04-15 [firmware] Refractor
    - Made term naming more coherent. Previously `entry` has ambiguous
    meaning
    * KVpair: the valid part of a allocated block, which a bucket points
    to
    * Entry: the part of a KVpair after the strokes
    - Abstracts the stroage (currently flash), UI/display, and keyboard
    hooks' interfaces, to facilitate easier porting to other platforms
    - `const` and `static`-ified the core
    - Some other small fixes
    [flash.c]
2021-04-15 [firmware] Add config options for features
    ... to disable dictionary editing, screens, and/or dictionary loading
    thru mass storage device
2021-04-18 [firmware] Unmagicify `*` & fix case handling bug
2021-04-19 [firmware] MSD flashing fix
    Fix incorrect UF2 format checking introduced in 4744a00
    [flash.c]
2021-04-24 [compiler] Update & auto merging dictionaries
    - Add the ability to use multiple input files when compiling and
    automatically merging them, printing conflict messages when necessary
    - Revert UF2 format to normal
    - Remove `BAT_STENO:{ADD,EDIT,REMOVE}_TRANSLATION` commands, and simply
    use `PLOVER:ADD_TRANSLATION` as dictionary editing command
    [main.rs]
2021-04-24 [compiler] Add compiled simple rules
    - Remove word list cuz we can't use that anywhere
    - Compile simple rules (exception from regex rules) into 64KiB sized binary hashmap
    - Rules comes from https://github.com/nimble0/dotterel/blob/master/app/src/main/assets/orthography/english.simple.json
    - Load rules at `0xF30000`
    [steno.kicad_pcb, steno.sch]
2021-05-19 [compiler] Use nom for entry parsing
    - Some parts of `lalrpop` doesn't work properly, so we use `nom` for the
    moment
    - Ignoring (i.e. not including) entries that can't be parsed
    clippy
    [main.rs]
2021-07-22 [PCB] Add folded bat design and production files
    [ble_steno_left.csv, ble_steno_left.kicad_pcb, ble_steno_left.sch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]
2021-07-22 [firmware] rework configs
    - add option to disable internal orthography engine
    - rework flash/console logging
    [config.h]
2021-07-22 [compiler] fix parsing of keycodes
    [main.rs]
2021-07-22 [compiler] make dict patching a feature
    Dictionary patching is no longer needed by default, as the internal
    orthography engine should do the work. But this is left in as a feature
    so that experiments can be done easily
    [main.rs]
2021-07-22 [fw.zmk] use `/chosen` node for spi flash
    use the `zmk,steno_flash` property to denote what flash driver to use,
    as there can be multiple different types of flash drivers and the flash
    can also live on different buses (QSPI vs. normal SPI)
2022-02-11 update(docs): Add simple docs and pics for recent PCBs, add firmware name
